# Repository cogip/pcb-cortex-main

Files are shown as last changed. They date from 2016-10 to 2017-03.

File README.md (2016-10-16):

# Cortex motherboard Kicad project

## Install Kicad 4 on Ubuntu

```bash
sudo apt-add-repository ppa:js-reynaud/kicad-4
sudo apt-get update
sudo apt-get install kicad
```

## To open the project

Multiple projects are available:

```bash
kicad cortex_main.pro
kicad minus_main.pro
```

## Quick tutorial

- [WebCast on Youtube](https://www.youtube.com/watch?v=zK3rDhJqMu0)

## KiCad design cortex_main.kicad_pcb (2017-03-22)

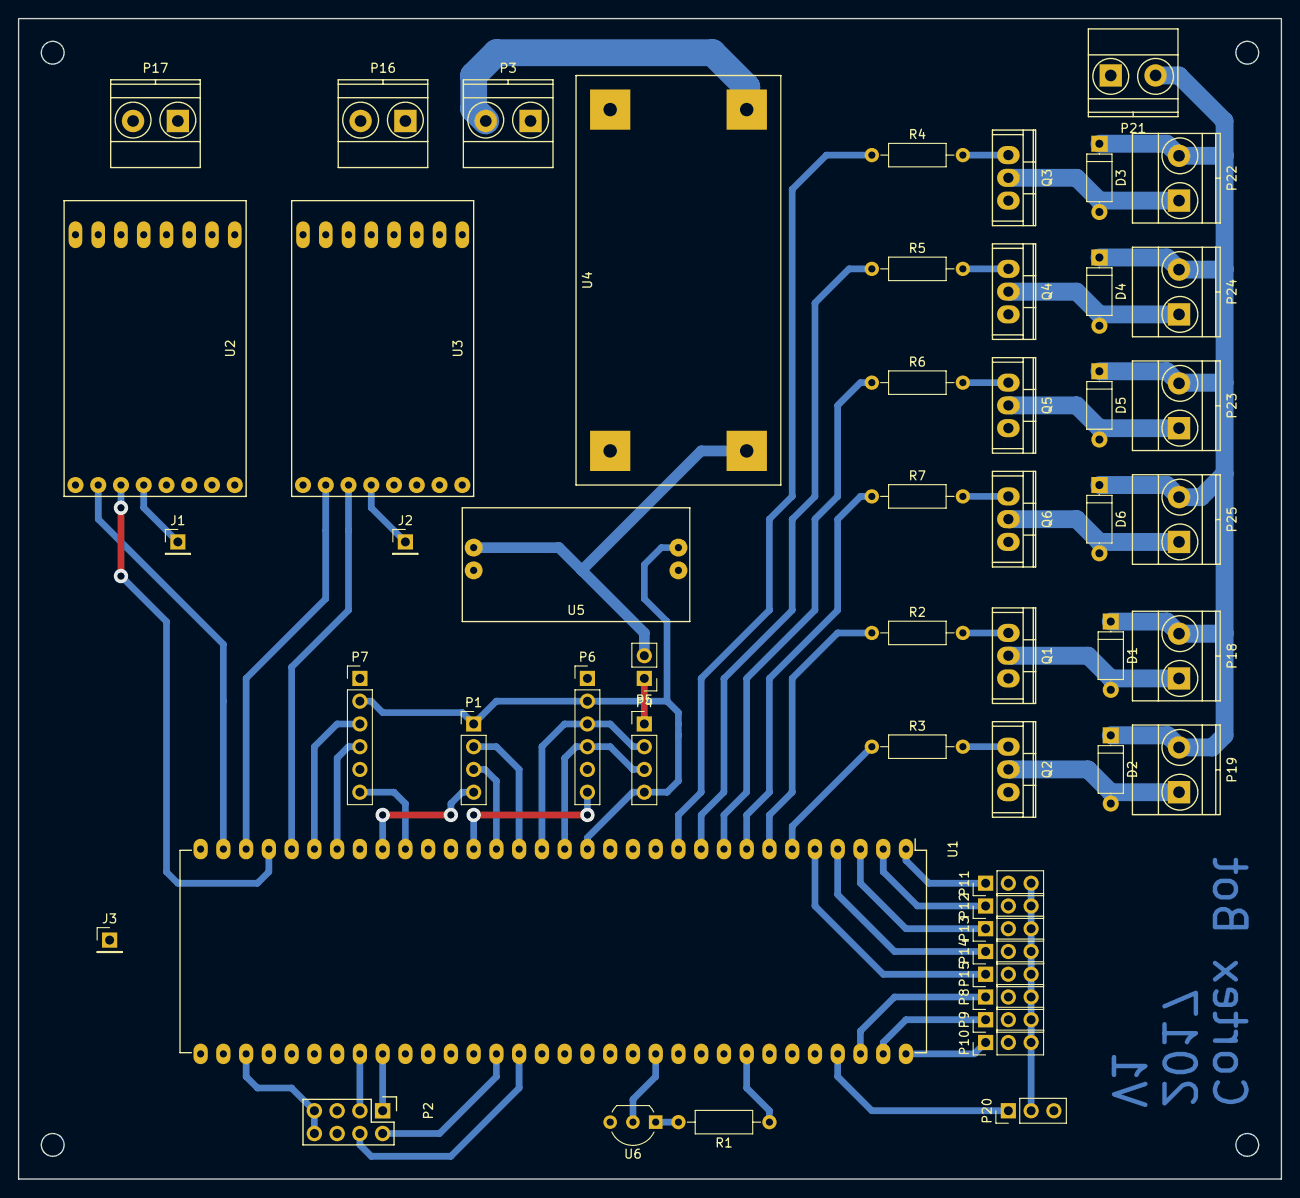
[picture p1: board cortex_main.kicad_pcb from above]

Board: 2 copper layers, 141.0 x 129.5 mm, 53 parts (0 on the bottom side), 56 nets.

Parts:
D1, D2, D3, D4, D5, D6: 1N4001; D_A-405_P7.62mm_Horizontal
J1, J2, J3: TEST_1P; Pin_Header_Straight_1x01_Pitch2.54mm
P1, P4: CONN_01X04; Pin_Header_Straight_1x04_Pitch2.54mm
P2: CONN_02X04; Pin_Header_Straight_2x04
P3, P16, P17, P18, P19, P21, P22, P23, P24, P25: CONN_01X02; TerminalBlock_Pheonix_MKDS1.5-2pol
P5: CONN_01X02; Pin_Header_Straight_1x02_Pitch2.54mm
P6, P7: CONN_01X06; Pin_Header_Straight_1x06_Pitch2.54mm
P8, P9, P10, P11, P12, P13, P14, P15, P20: CONN_01X03; Pin_Header_Straight_1x03_Pitch2.54mm
Q1, Q2, Q3, Q4, Q5, Q6: IRF540N; TO-220
R1: 1K; R_Axial_DIN0207_L6.3mm_D2.5mm_P10.16mm_Horizontal
R2, R3, R4, R5, R6, R7: 100R; R_Axial_DIN0207_L6.3mm_D2.5mm_P10.16mm_Horizontal
U1: socket_leon_x3_dil64; DIP-64_W22.86mm_LongPads
U2, U3: socket_pololu_24v12; pololu_24v12_dip
U4: socket_lm2596_mod; lm2596s_mod
U5: socket_ams1117-3V3_mod; ams1117-3V3_mod
U6: MCP100-D; TO-92_Inline_Wide

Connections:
+3V3: P1.1, P2.7, P2.8, P4.4, P6.2, P7.2, P20.1, U1.15, U1.25, U1.35, U1.45, U1.53, U1.61, U5.3, U6.2
+5V: P5.2, P20.3, U4.3, U5.1
+24V: P3.2, U2.1, U2.2, U2.15, U2.16, U3.1, U3.2, U3.15, U3.16, U4.1
/Sheet_Connectors/RGB_LEDEN_L: P6.6, U1.20
/Sheet_Connectors/RGB_LEDEN_R: P7.6, U1.23
/Sheet_Connectors/SCL_C: P4.2, P6.3, U1.17
/Sheet_Connectors/SCL_D: P7.3, U1.27
/Sheet_Connectors/SDA_C: P4.3, P6.4, U1.16
/Sheet_Connectors/SDA_D: P7.4, U1.26
/Sheet_Connectors/UART_DBG_RXD: P1.3, U1.19
/Sheet_Connectors/UART_DBG_TXD: P1.2, U1.18
/Sheet_MCU/CMD_ARMMOTOR_L: R2.1, U1.7
/Sheet_MCU/CMD_ARMMOTOR_R: R3.1, U1.6
/Sheet_MCU/CMD_PUMP_BL: R6.1, U1.9
/Sheet_MCU/CMD_PUMP_BR: R7.1, U1.8
/Sheet_MCU/CMD_PUMP_TL: R4.1, U1.11
/Sheet_MCU/CMD_PUMP_TR: R5.1, U1.10
/Sheet_MCU/DIR_L: U1.31, U2.10
/Sheet_MCU/DIR_R: U1.30, U3.10
/Sheet_MCU/PWM_L: U1.29, U2.11
/Sheet_MCU/PWM_R: U1.28, U3.11
ENCA_L: P2.3, U1.40
ENCA_R: P2.4, U1.47
ENCB_L: P2.1, U1.41
ENCB_R: P2.2, U1.46
GND: J3.1, P1.4, P2.5, P2.6, P3.1, P4.1, P5.1, P6.1, P7.1, P8.2, P9.2, P10.2, P11.2, P12.2, P13.2, P14.2, P15.2, P21.1, Q1.3, Q2.3, Q3.3, Q4.3, Q5.3, Q6.3, U1.14, U1.24, U1.34, U1.44, U1.52, U1.60, U2.7, U2.8, U2.9, U3.7, U3.8, U3.9, U4.2, U4.4, U5.2, U5.4, U6.3
IR_VCC: P8.3, P9.3, P10.3, P11.3, P12.3, P13.3, P14.3, P15.3, P20.2
IR_VIN_0: P8.1, U1.62
IR_VIN_1: P9.1, U1.63
IR_VIN_2: P10.1, U1.64
IR_VIN_3: P11.1, U1.1
IR_VIN_4: P12.1, U1.2
IR_VIN_5: P13.1, U1.3
IR_VIN_6: P14.1, U1.4
IR_VIN_7: P15.1, U1.5
unnamed: J1.1, U2.12
unnamed: J2.1, U3.12
unnamed: Q1.1, R2.2
unnamed: Q2.1, R3.2
unnamed: Q3.1, R4.2
unnamed: Q4.1, R5.2
unnamed: Q5.1, R6.2
unnamed: Q6.1, R7.2
unnamed: R1.1, U1.57
unnamed: R1.2, U6.1
OUTA_L: P17.1, U2.3, U2.4
OUTA_R: P16.1, U3.3, U3.4
OUTB_L: P17.2, U2.5, U2.6
OUTB_R: P16.2, U3.5, U3.6
OUTN_ARMMOTOR_L: D1.2, P18.1, Q1.2
OUTN_ARMMOTOR_R: D2.2, P19.1, Q2.2
OUTN_PUMP_BL: D5.2, P23.1, Q5.2
OUTN_PUMP_BR: D6.2, P25.1, Q6.2
OUTN_PUMP_TL: D3.2, P22.1, Q3.2
OUTN_PUMP_TR: D4.2, P24.1, Q4.2
OUTP_ARMMOTOR_L: D1.1, D2.1, D3.1, D4.1, D5.1, D6.1, P18.2, P19.2, P21.2, P22.2, P23.2, P24.2, P25.2

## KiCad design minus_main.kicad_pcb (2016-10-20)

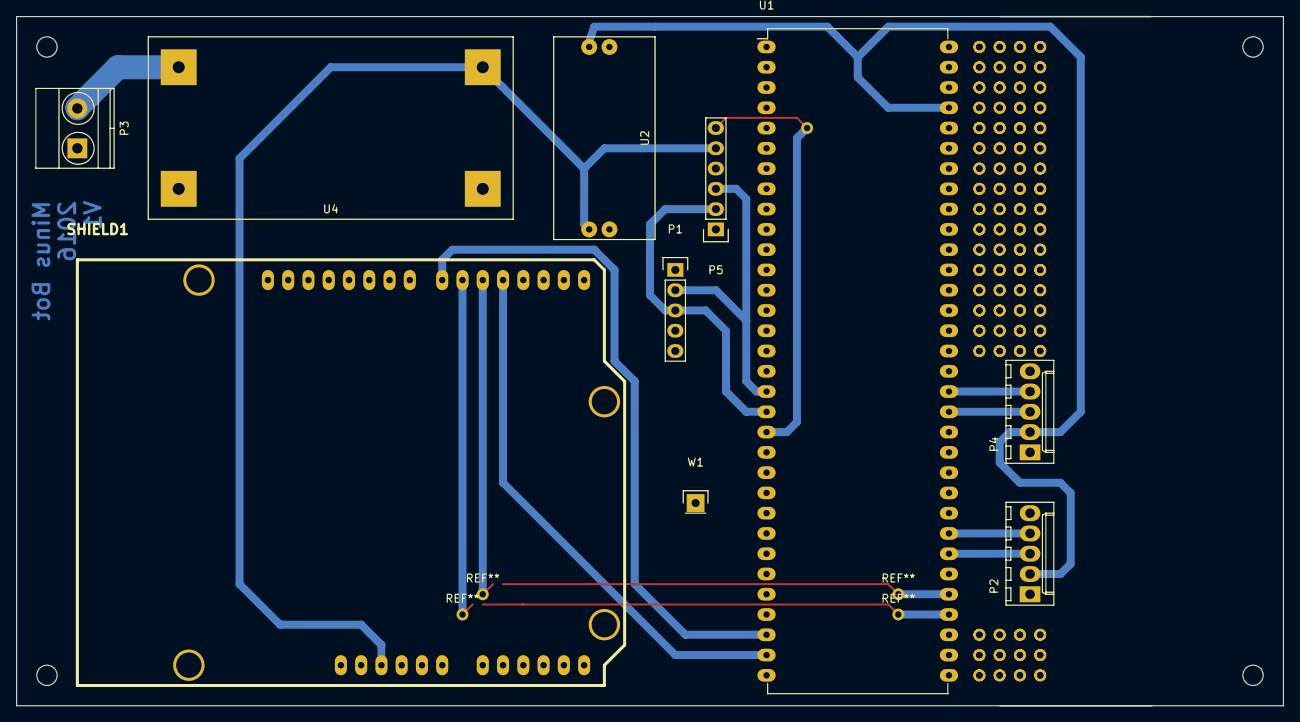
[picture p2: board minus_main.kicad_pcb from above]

Board: 2 copper layers, 158.8 x 86.4 mm, 10 parts (0 on the bottom side), 15 nets.

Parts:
P1: CONN_01X05; Pin_Header_Straight_1x05
P2, P4: CONN_01X05; Molex_KK-6410-05_05x2.54mm_Straight
P3: CONN_01X02; TerminalBlock_Pheonix_MKDS1.5-2pol
P5: CONN_01X06; Pin_Header_Straight_1x06
SHIELD1: arduino_shield
U1: socket_leon_x3_dil64; DIP-64_W22.86mm_LongPads
U2: socket_ams1117-3V3_mod; ams1117-3V3_mod
U4: socket_lm2596_mod; lm2596s_mod
W1: TEST_1P; Pin_Header_Straight_1x01

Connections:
+3V3: P2.2, P4.2, U1.61, U2.3
+5V: P5.5, SHIELD1.5V, U2.1, U4.3
+24V: P3.2, U4.1
/Sheet_Connectors/BT_KEY: P5.6, U1.20
/Sheet_Connectors/BT_RXD: P1.3, P5.2, U1.19
/Sheet_Connectors/BT_TXD: P1.2, P5.3, U1.18
/Sheet_MCU/DIR_L: SHIELD1.7, U1.30
/Sheet_MCU/DIR_R: SHIELD1.4, U1.31
/Sheet_MCU/PWM_L: SHIELD1.6, U1.36
/Sheet_MCU/PWM_R: SHIELD1.5, U1.37
ENCA_L: P2.3, U1.39
ENCA_R: P4.3, U1.46
ENCB_L: P2.4, U1.40
ENCB_R: P4.4, U1.47
GND: P1.4, P2.1, P3.1, P4.1, P5.4, SHIELD1.GND1, SHIELD1.GND2, U1.14, U1.24, U1.34, U1.44, U1.52, U1.60, U2.2, U2.4, U4.2, U4.4, W1.1

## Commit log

2016-07-26 initial commit
    a library for Leon Instrument X3-DIL64 module as been created.
    [main_board.kicad_pcb, main_board.sch]
2016-07-30 lib: rename to be more generic
    [main_board.sch]
2016-07-30 all: add pololu 24v12 footprint and symbol
    [main_board.kicad_pcb, main_board.sch]
2016-07-30 pcb: add dimensions
    same as geonobot "xmega_board" pcb.
    [main_board.kicad_pcb, main_board.sch]
2016-07-30 pcb: fix width size
    [main_board.kicad_pcb]
2016-07-31 pcb: routing test and holes
    [main_board.kicad_pcb]
2016-08-01 all: add UARTC0 (debug link)
    [main_board.kicad_pcb, main_board.sch]
2016-08-03 sch: move to hierarchical schematic and multiple sheets
    [main_board.kicad_pcb, main_board.sch, main_board_conn.sch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]
2016-10-15 bot_parts: add lm2596s module symbol & footprint
2016-10-15 sch: add main_board_psu
    subsheet contains PSU relevant parts
    [main_board.kicad_pcb, main_board.sch, main_board_conn.sch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]
2016-10-15 all: rename project for multiple bots support
    [cortex_main.kicad_pcb, cortex_main.sch, cortex_main_conn.sch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]
2016-10-15 all: introduce minus main project
    [minus_main.kicad_pcb, minus_main.sch, minus_main_conn.sch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]
2016-10-15 libs: move bot_part footprint in subdir
    this is required by footprint editor to correctly view parts
    of a lib, otherwise all footprint from multiple lib will be
    visible from one lib...
2016-10-15 libs: add arduino shield library
    easy integration of opensource lib from:
    http://www.thingiverse.com/thing:9630
    this will ease the dfrobot hbridge shield.
2016-10-15 minus: h-bridge: switch to DFRobot L298P shield
    previously, pololu were on schematic.
    [minus_main.kicad_pcb, minus_main.sch, minus_main_conn.sch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]
2016-10-16 minus: add encoder connectors
    pcb update
    [minus_main.kicad_pcb, minus_main_conn.sch, minus_main_mcu.sch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]
2016-10-16 lib: new ams1117-3V3 symbol & footprint
2016-10-16 minus: add 3V3 module on schematic & pcb
    [minus_main.kicad_pcb, minus_main_psu.sch]
2016-10-16 minus: add a lots of pads for development
    [minus_main.kicad_pcb]
2016-10-20 minus: add BT HC-05 module on schematic & pcb
    [minus_main.kicad_pcb, minus_main.sch, minus_main_conn.sch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]
2016-10-20 minus: add a GND testpad
    This is intented to get an easy access to GND reference
    for electrical measurement on board.
    [minus_main.kicad_pcb, minus_main_psu.sch]
2017-02-22 cortex: update to 120x120mm PCB size
    To match final mechanical constraints
    [cortex_main.kicad_pcb]
2017-02-22 cortex: add 3V3 regulator
    [cortex_main.kicad_pcb, cortex_main.sch, cortex_main_conn.sch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]
2017-02-22 cortex: fix left engine encoder gpio
    wiring was shift on minus, now it to match current fw gpio muxing
    [cortex_main_mcu.sch]
2017-02-22 cortex: add I2C bus & connectors to SD21 extension board
    [cortex_main.kicad_pcb, cortex_main.sch, cortex_main_conn.sch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]
2017-02-22 lib: new MCP100-D symbol & footprint
    Reset signal generator from Microchip
    http://ww1.microchip.com/downloads/en/DeviceDoc/11187f.pdf
2017-02-22 cortex: add MCP100-D to reset MCU
    [cortex_main.kicad_pcb, cortex_main.sch, cortex_main_conn.sch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]
2017-02-26 cortex: rename main I2C bus to specify PortC
    This is in prevision of introducing another I2C bus
    on another Port.
    [cortex_main.sch, cortex_main_conn.sch, cortex_main_mcu.sch]
2017-02-26 cortex: add I2CD and RGB sensors
    schematic only
    [cortex_main.sch, cortex_main_conn.sch, cortex_main_mcu.sch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]
2017-02-26 cortex: add SD21 I2C address on schematic
    [cortex_main_conn.sch]
2017-02-26 cortex: pcb: place RGB connectors
    [cortex_main.kicad_pcb, cortex_main_conn.sch, cortex_main_mcu.sch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]
2017-02-26 cortex: fixup MCU sheet signals direction
    for cosmetics only. unfortunately, this is not propagated on
    root sheet... hum.
    [cortex_main_mcu.sch]
2017-02-26 cortex: add Sharp IR sensors connectors
    on schematic & pcb.
    [cortex_main.kicad_pcb, cortex_main.sch, cortex_main_conn.sch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]
2017-02-26 cortex: add Motors connectors
    on sch & pcb.
    [cortex_main.kicad_pcb, cortex_main.sch, cortex_main_conn.sch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]
2017-02-26 cortex: pcb: start output layout
    [cortex_main.kicad_pcb, cortex_main_conn.sch, cortex_main_mcu.sch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]
2017-02-26 cortex: pcb move on
    some new stuff. sd21, and few routing tests
    [cortex_main.kicad_pcb]
2017-02-26 cortex: new pin muxing to ease pcb layout
    pcb layout progress as well
    [cortex_main.kicad_pcb, cortex_main_conn.sch, cortex_main_mcu.sch]
2017-02-26 cortex: add Arms Motor mosfet drivers
    [cortex_main.kicad_pcb, cortex_main.sch, cortex_main_conn.sch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]
2017-02-26 cortex: add clamping diode to arm motor mosfet
    [cortex_main.kicad_pcb, cortex_main.sch, cortex_main_conn.sch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]
2017-02-26 cortex: update UART connector
    move to 4pins and wire the +3V3 supply for comm module.
    [cortex_main.kicad_pcb, cortex_main_conn.sch, cortex_main_psu.sch]
2017-03-13 cortex: sch & pcb updates after first review
    - add testpad on pololu /rst signals
    - fix rotary encoders pinout: [+,-,A,B]
    - add jumper to choose 3V3 or 5V for IR sharp sensors
    [cortex_main.kicad_pcb, cortex_main_conn.sch, cortex_main_motors.sch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]
2017-03-14 cortex: add vacuum pump mosfets
    on both schematic & layout.
    [cortex_main.kicad_pcb, cortex_main.sch, cortex_main_conn.sch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]
2017-03-16 cortex: update arm motors PSU
    PCB is almost done.
    [cortex_main.kicad_pcb, cortex_main_conn.sch, cortex_main_mcu.sch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]
2017-03-16 cortex: add gnd test pad and text on PCB
    [cortex_main.kicad_pcb, cortex_main_conn.sch]
2017-03-22 cortex: enhance pcb routing
    power track are now bigger
    [cortex_main.kicad_pcb]
